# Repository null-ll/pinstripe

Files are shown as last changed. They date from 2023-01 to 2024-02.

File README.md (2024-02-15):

# Pinstripe

Full
***Not everything has been implemented/tested fully. Build at your own risk!***

Through-hole 60% keyboard with arrow keys, a rotary encoder, a SSD1306 OLED display, and a DS1307 I2C RTC module.

OLED displays 24-hour time and [bongo cat animation](https://github.com/nwii/oledbongocat) in default keymap. 

## Supported Layouts
Layout
> View on [Keyboard Layout Editor](http://www.keyboard-layout-editor.com/#/gists/76d009fbf60b83c250d901e28f7cc0d1)

### Default Layout
> View on [Keyboard Layout Editor](http://www.keyboard-layout-editor.com/#/gists/a1eb12ef4bd2b7b5ea2a67abed068752)

## BOM
| Ref | Component | Qty | Notes |
| --- | --- | --- | ----- |
| C1, C2  | 22pF Capacitor | 2 
| C3, C4  | 0.1uF Capacitor | 2
| C5 | 4.7uF Capacitor | 1 
| D1-66, D71 | 1n4148 Diode | 68
| D67, D68 | 3.6V Zener Diode | 2  | Keep separate from the 1n4148 diodes
| FUSE | 500mA Resettable fuse  | 1
| ISP | 6 pin header | 1
| USB | GCT USB4085 USB C port | 1
| POWER | 3mm LED | 1
| R1, R2  | 1.5k Resistor | 2 
| R3, R6  | 5.1k Resistor | 2 
| R4, R5  | 75 Resistor | 2 
| R7 | 10k Resistor | 1 
| U1 | ATmega32A | 1
| | 40 pin IC socket | 1
| RESET, BOOT | 6mm push button | 1
| Y1 | 16MHz Crystal | 1
| ROTARY ENCODER | EC11 Rotary encoder | 1
| OLED | SSD1306 128x64 OLED | 1 | Make sure the pins are in the order GND, VCC, SCL, SDA from left to right. Some versions have the pins arranged differently.
| DS1307  | Adafruit DS1307 Module | 1
| | Knob | 1
| | CR1220 Battery | 1 | Battery for RTC
| | M2 10+3mm standoff | 5 | For mounting the acrylic guard
| | M2 6mm screw | 5 | For mounting the acrylic guard
| | M2 6mm standoff | 10 | Holds the PCB and bottom plate together
| | M2 4mm screw | 17 | Holds the PCB and bottom plate together
| | M2 Nut | 4 | For mounting the OLED cover
| | M2 7mm screw | 4 | For mounting the OLED cover
| | Pinstripe PCB | 1
| | Bottom plate | 1
| | Switch plate | 1
| | Acrylic guard | 1 
| | Acrylic OLED cover | 1 | I used dark gray translucent acrylic which masks the OLED module's PCB pretty well.
| | Rubber Feet | 4

## Build Guide
WIP

## Setting the Time
In the default keymap, pressing Fn+T (custom keycode KC_SETTIME) will put the keyboard into time setting mode. Enter the time in the form HHMMSS (hour, minute, second) in this mode to set the RTC time. This time will be stored in the RTC module, even when the keyboard is powered off, for as long as the battery lasts.

For custom keymaps, add the keycode KC_SETTIME to a key (preferably not on the base layer).

## Images
Front
Back
OLED
Pinstripe
Pinstripe

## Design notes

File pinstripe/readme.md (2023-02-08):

# Pinstripe

A through-hole 65% keyboard with a rotary encoder, SSD1306 128x64 OLED, and a DS1307 RTC module.

* Keyboard Maintainer: [null-ll](https://github.com/null-ll)
* Hardware Supported: atmega32a
* Hardware Availability: [Github](https://github.com/null-ll/basketweave)

Make example for this keyboard (after setting up your build environment):

    make pinstripe:default

See the [build environment setup](https://docs.qmk.fm/#/getting_started_build_tools) and the [make instructions](https://docs.qmk.fm/#/getting_started_make_guide) for more information. Brand new to QMK? Start with our [Complete Newbs Guide](https://docs.qmk.fm/#/newbs).

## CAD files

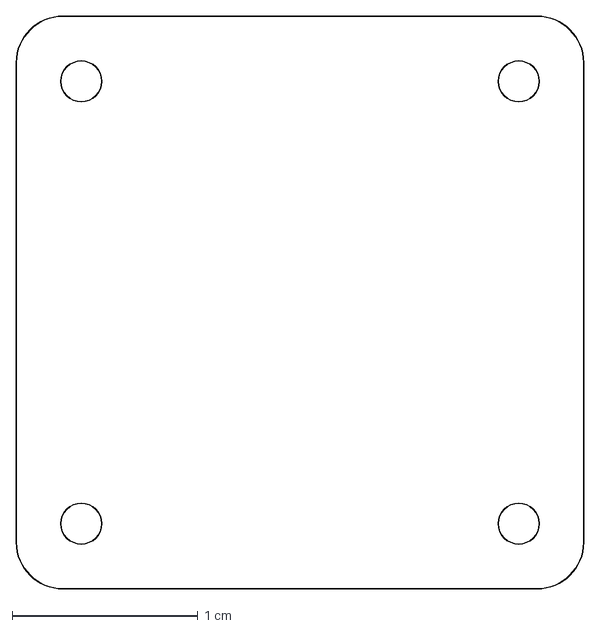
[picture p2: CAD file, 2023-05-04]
oled_cover.dxf
3.05 x 3.08 cm

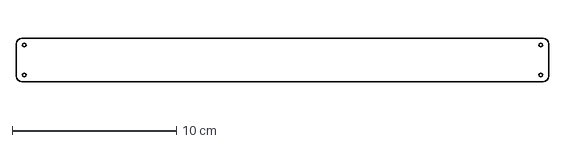
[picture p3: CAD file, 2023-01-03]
pcb/pinstripe/acrylic_guard.dxf
32.4 x 2.62 cm

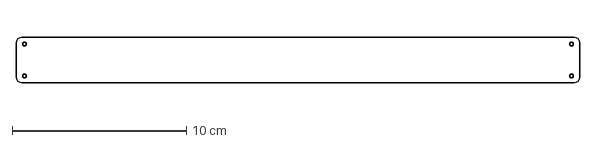
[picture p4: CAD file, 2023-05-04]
acrylic_guard.dxf
32.4 x 2.62 cm

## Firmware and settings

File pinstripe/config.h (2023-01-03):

/* Copyright 2021 null-ll
 *
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
 * You should have received a copy of the GNU General Public License
 * along with this program.  If not, see <http://www.gnu.org/licenses/>.
 */

#pragma once

#include "config_common.h"

#define VENDOR_ID       0xFEED
#define PRODUCT_ID      0x8427
#define DEVICE_VER      0x0001
#define MANUFACTURER    Noah L
#define PRODUCT         Pinstripe

/* key matrix size */
#define MATRIX_ROWS 5
#define MATRIX_COLS 15

#define MATRIX_ROW_PINS { B2, A1, B1, A0, B0 }
#define MATRIX_COL_PINS { D6, D5, C2, C3, C4, C5, D0, A7, A6, A5, A4, B4, A3, B3, A2 }
#define UNUSED_PINS

/* COL2ROW, ROW2COL*/
#define DIODE_DIRECTION COL2ROW

/* Debounce reduces chatter (unintended double-presses) - set 0 if debouncing is not needed */
#define DEBOUNCE 5

/* Mechanical locking support. Use KC_LCAP, KC_LNUM or KC_LSCR instead in keymap */
#define LOCKING_SUPPORT_ENABLE
/* Locking resynchronize hack */
#define LOCKING_RESYNC_ENABLE

/* If defined, GRAVE_ESC will always act as ESC when CTRL is held.
 * This is userful for the Windows task manager shortcut (ctrl+shift+esc).
 */
// #define GRAVE_ESC_CTRL_OVERRIDE

#define ENCODERS_PAD_A { C7 }
#define ENCODERS_PAD_B { C6 }
#define ENCODER_RESOLUTION 4
#define TAP_CODE_DELAY 10

#ifdef OLED_DRIVER_ENABLE
    #define OLED_DISPLAY_128X64
    // #define OLED_FONT_H "glcdfont_pinstripe.c"
    // #define OLED_FONT_END 255
#endif

#define DS1307_ADDR (0x68 << 1)

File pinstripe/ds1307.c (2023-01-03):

#include "ds1307.h"
#include "i2c_master.h"

void set_time(uint8_t h, uint8_t m, uint8_t s) {
    uint8_t data[] = {
        ((s % 10) | ((s / 10) << 4)) & 0x7F,
        ((m % 10) | ((m / 10) << 4)) & 0x7F,
        ((h % 10) | ((h / 10) << 4)) & 0x3F,
        0, 0, 0, 0, 0
    }; // 24-hour mode
    i2c_writeReg(DS1307_ADDR, 0, data, 8, 100);
}

void get_time(uint8_t *h, uint8_t *m, uint8_t *s) {
    uint8_t data[3];
    i2c_readReg(DS1307_ADDR, 0, data, 3, 100);
    i2c_stop();
    *s = (data[0] & 0b1111) + ((data[0] & 0b1110000) >> 4) * 10;
    *m = (data[1] & 0b1111) + ((data[1] & 0b1110000) >> 4) * 10;
    *h = (data[2] & 0b1111) + ((data[2] & 0b0110000) >> 4) * 10;
}

// void set_date(uint8_t d, uint8_t m){
//     uint8_t data[] = {
        
//     };
// }

// void get_date(uint8_t *d, uint8_t *m) {
//     uint8_t date[3];
//     i2c_readReg(DS1307_ADDR, 4, data, 3, 100);
    
// }

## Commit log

2023-05-04 Add acrylic guard
    [acrylic_guard.dxf]
2023-05-04 Add OLED cover
    [oled_cover.dxf]

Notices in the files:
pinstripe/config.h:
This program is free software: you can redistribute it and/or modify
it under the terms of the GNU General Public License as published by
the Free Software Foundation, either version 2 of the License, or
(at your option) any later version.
